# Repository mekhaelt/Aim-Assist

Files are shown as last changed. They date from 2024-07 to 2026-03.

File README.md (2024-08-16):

# Aim Assist

<p align="center">
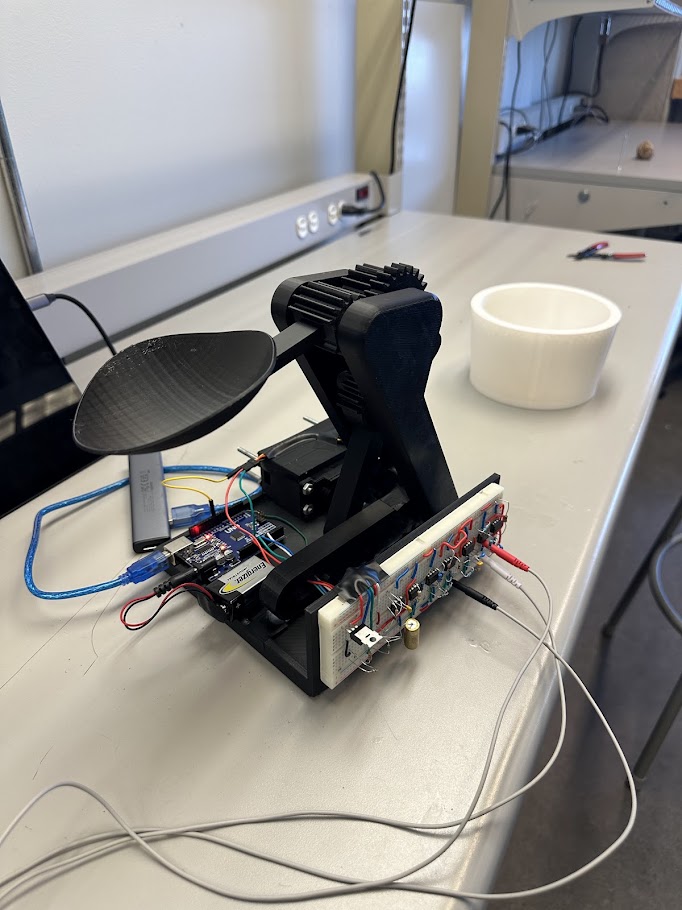
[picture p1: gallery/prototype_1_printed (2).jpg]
  
</p>

## Overview

The Aim Assist project develops a prosthetic arm that replicates the biomechanics of a human arm to shoot a basketball. Designed for individuals with upper limb disabilities or amputations, this prosthetic enhances physical activity and psychological well-being by enabling participation in sports.

## Features

-   **Biomechanical Accuracy**: Mimics natural arm movements including elbow and shoulder flexion and wrist flick.
-   **Customizable Settings**: Engineered to adjust for optimal release speed, angle, and spin.
-   **Arduino Integration**: Uses Arduino Uno to synchronize motor movements with EMG signal inputs for real-time responsiveness.

## Technology Stack

-   **Mechanical Design**: Gears and linkages to simulate arm motion.
-   **Electronics**: Arduino Uno and Servo Motors (HS-805BB).
-   **Fabrication**: 3D printed with Polylactic Acid (PLA) for durability and lightness.

## Installation

```bash
git clone https://github.com/your-github/aim-assist.git
```

-   Assemble the hardware according to the diagrams provided in the `docs/assembly_instructions.pdf`.
-   Install Arduino dependencies.

## Usage

-   Attach the prosthetic arm following the personal fitting instructions.
-   Calibrate the EMG sensors as per the user guide.
-   Use the provided scripts to test and calibrate the shooting mechanism.

## Collaborators
- Raiyan A [Contact](mailto:raiyanjaz@gmail.com)
- Mekhael T [Contact](mailto:mekhaelt@gmail.com)

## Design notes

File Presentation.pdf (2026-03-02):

# Aim Assist

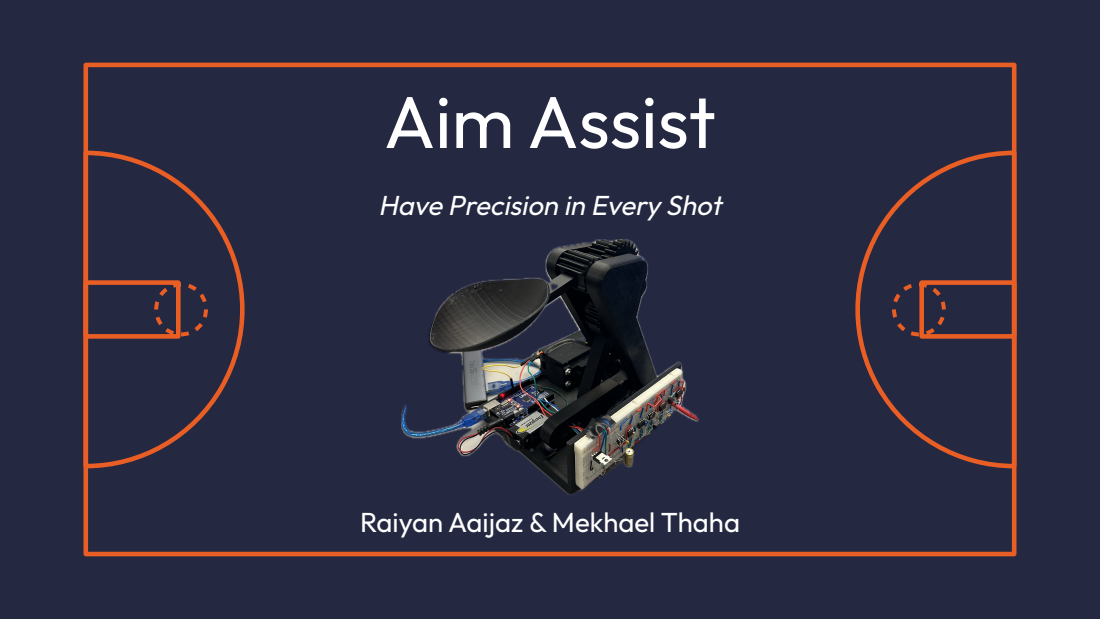
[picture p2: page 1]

Have Precision in Every Shot

Raiyan Aaijaz & Mekhael Thaha

# Objective and Requirements:

Develop a prosthetic arm capable of shooting a tennis ball-sized object with the technique of a basketball shot. The prosthetic should mimic the biomechanics of a human arm, ensuring consistent release speed, angle, and spin to achieve accurate and repeatable shots.

Torque: 2.57 N-m
Speed: 2.48 m/s
Range of Motion: 53 degree

# Engineering Requirements Calculations

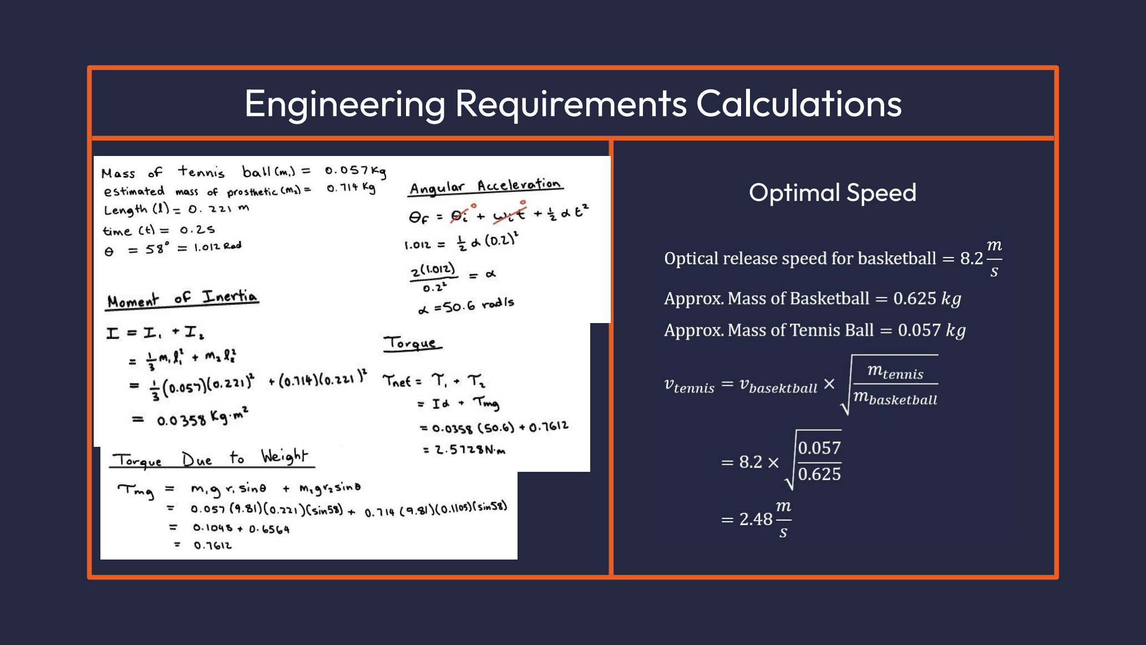
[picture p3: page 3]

## Optimal Speed

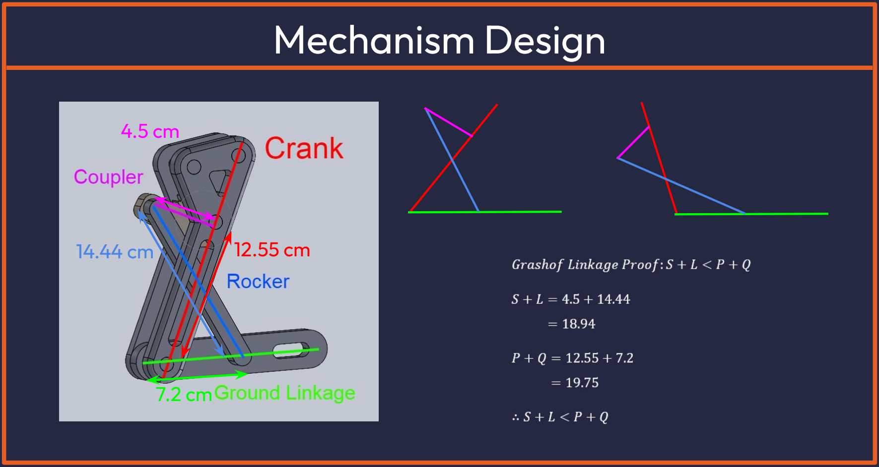
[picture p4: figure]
Mechanism Design

# Material and Servo Analysis

We chose 3D printing using Polylactic Acid (PLA) for all components due to several advantages:
- Ease of Manufacture: The gears designed have large teeth, which eliminates the need for high-precision cutting tools such as laser cutters.
- Material Properties: PLA is a lightweight material. When printed with increased infill, it provides the necessary sturdiness for our application.
- Cost-Effectiveness: PLA is a cost-effective choice for prototyping, allowing for efficient and economical production of design iterations.
Material Selection | Servo Selection
| Chosen Motor: HS-805BB Servo Motor ● Torque requirement needed for motor was 2.57 N-m ● HS-805BB gets 1.95 Nm at 4.8 V, 2.52 Nm at 6.0 V ● Though it is the heaviest option at 152 grams, it is manageable. Lighter motors are inadequate in other areas.

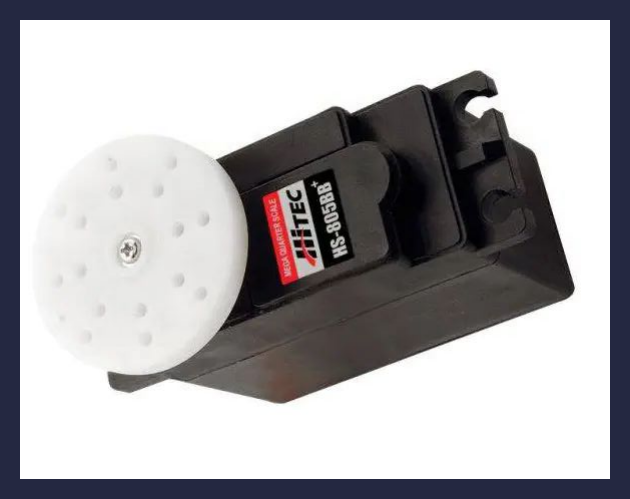
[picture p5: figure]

# Design Process and Iterations

Iteration 1:

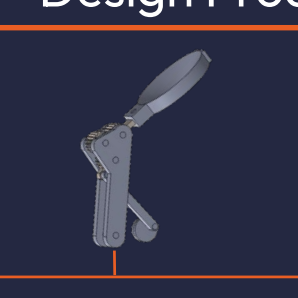
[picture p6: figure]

- Motor was planned to be connected at the linkage directly rather than the arm.
- The arms were kept stationary.
- Hand design was much larger than needed.

Iteration 2:

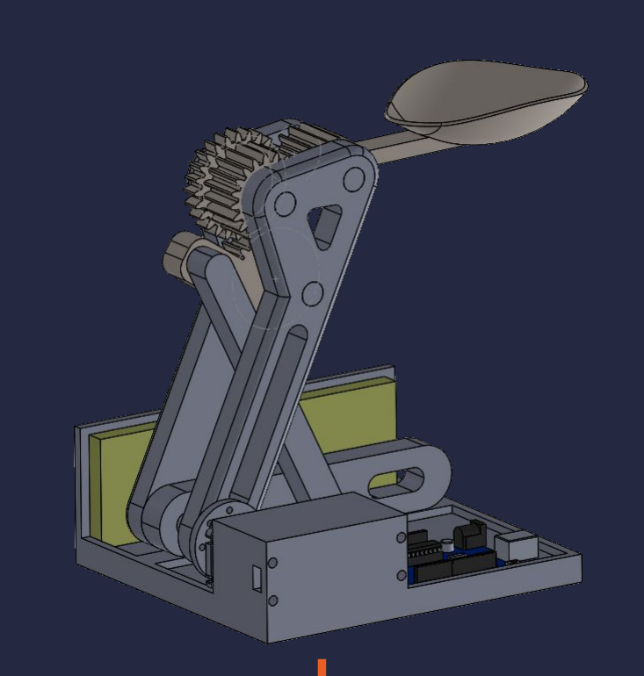
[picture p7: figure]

- Created a base to store Arduino, breadboard, and motor.
- Improved the hand design
- Moved the motor to add additional motion
- Scaled the design by 80% to minimize the weight.

# Arduino Code

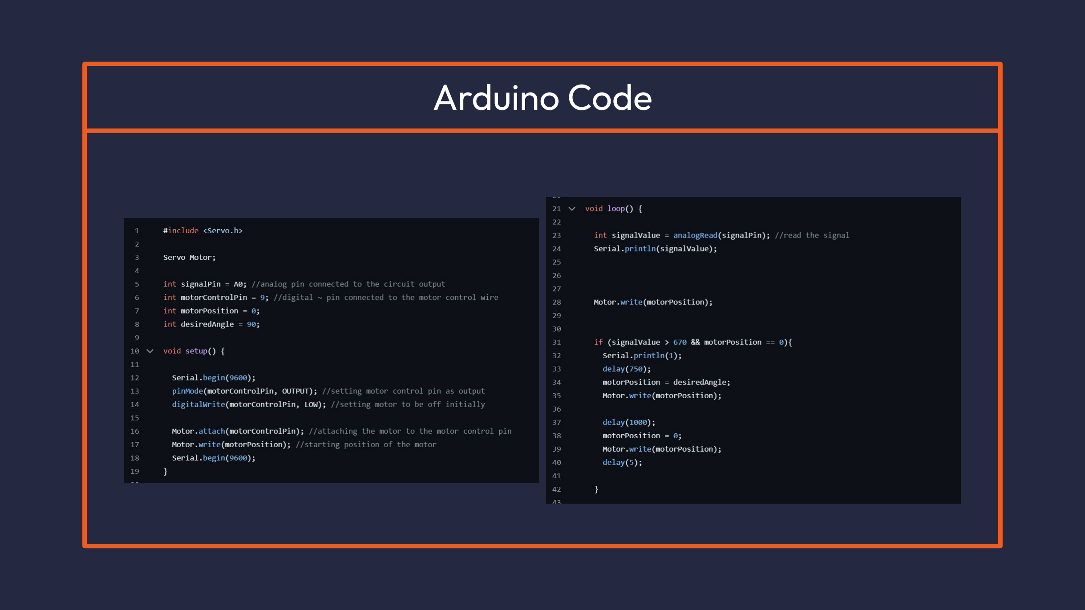
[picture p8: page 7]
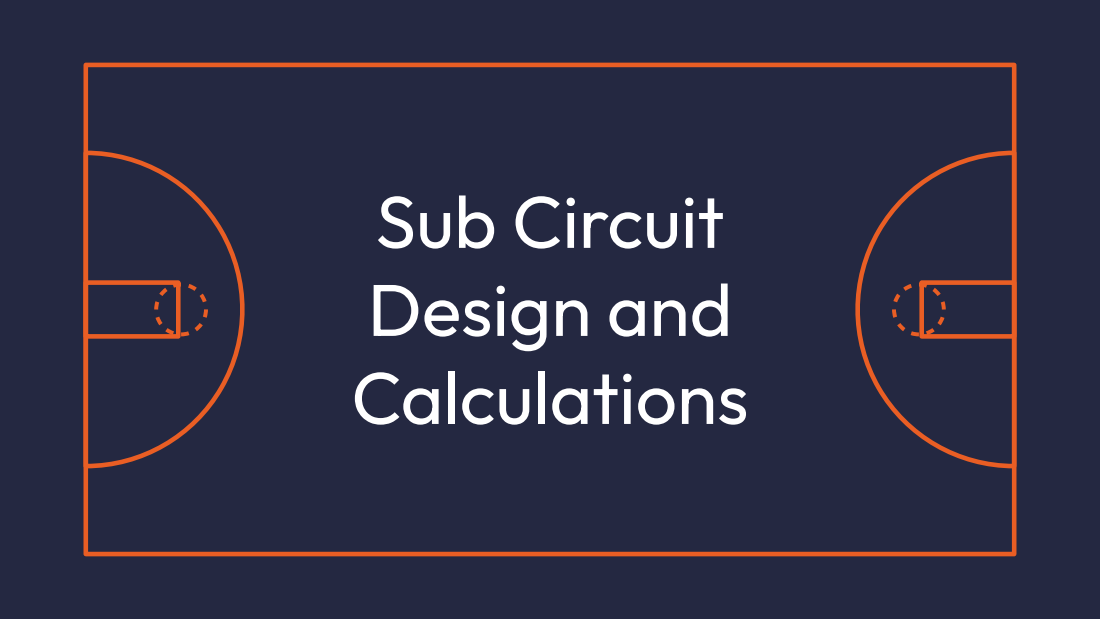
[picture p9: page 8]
Sub Circuit Design and Calculations

# Instrumentation Amplifier + Virtual Ground

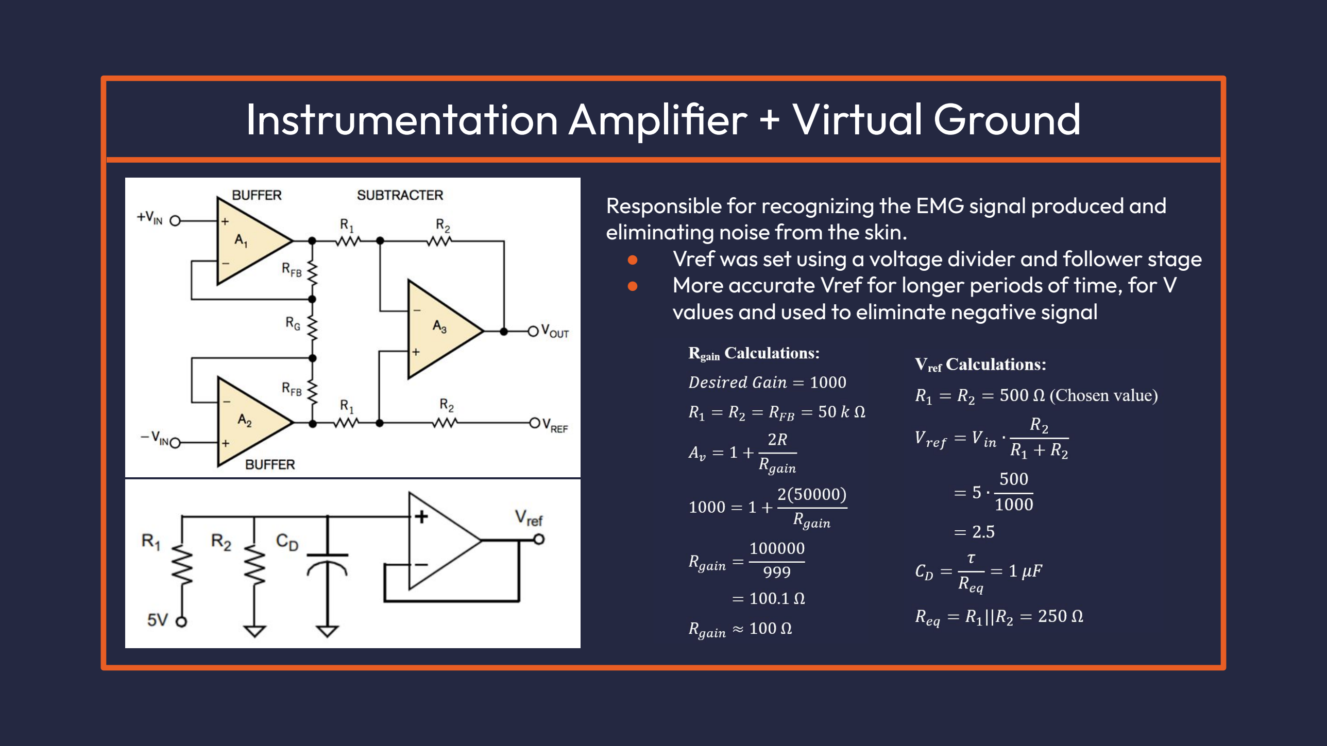
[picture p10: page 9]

Responsible for recognizing the EMG signal produced and eliminating noise from the skin.
- Vref was set using a voltage divider and follower stage
- More accurate Vref for longer periods of time, for V values and used to eliminate negative signal

# BandPass Filter (20 Hz and 500 Hz)

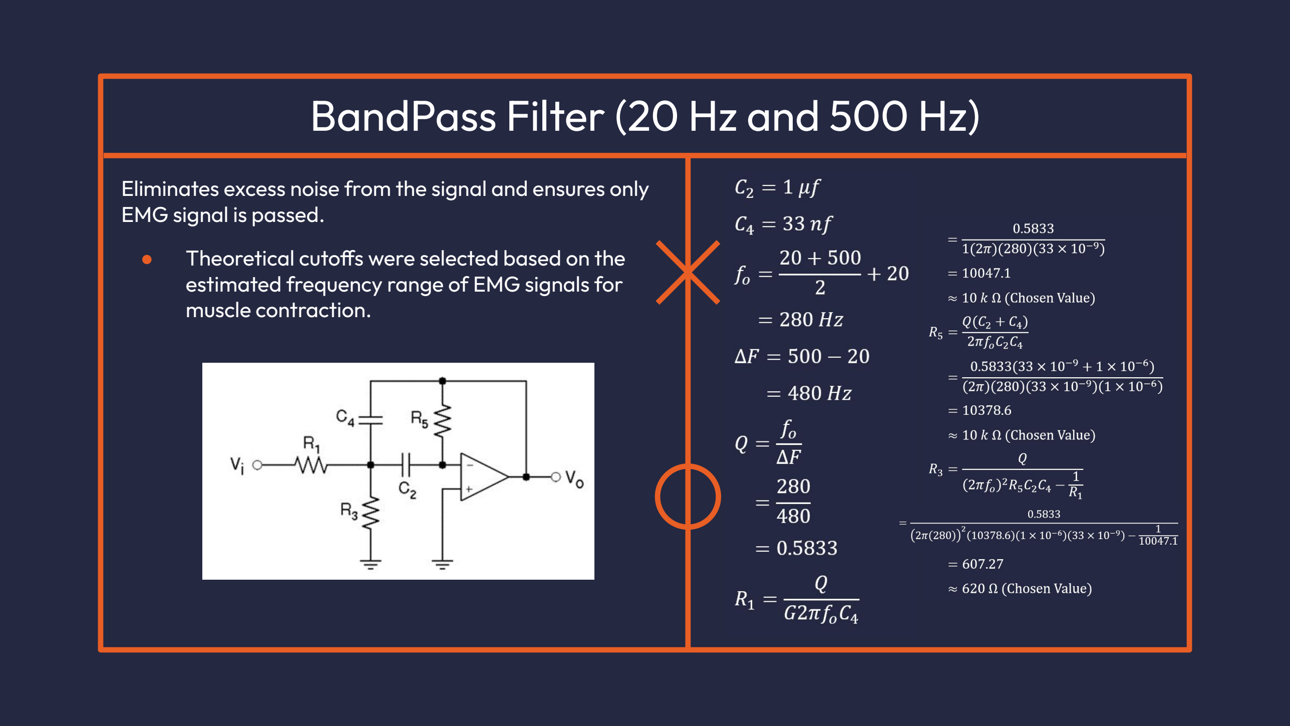
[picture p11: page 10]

Eliminates excess noise from the signal and ensures only EMG signal is passed.
- Theoretical cutoffs were selected based on the estimated frequency range of EMG signals for muscle contraction.

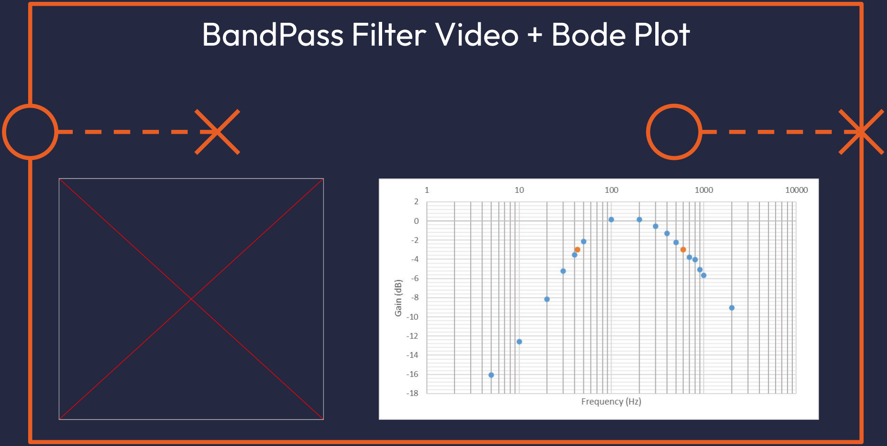
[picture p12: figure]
BandPass Filter Video + Bode Plot

# Full-Wave Rectifier

Responsible for cleaning up signal quality and emphasizing peaks of the EMG signal while maintaining integrity of the signal
- Gain of -1
- -2 from half wave rectifier
- +1 from summing amplifier

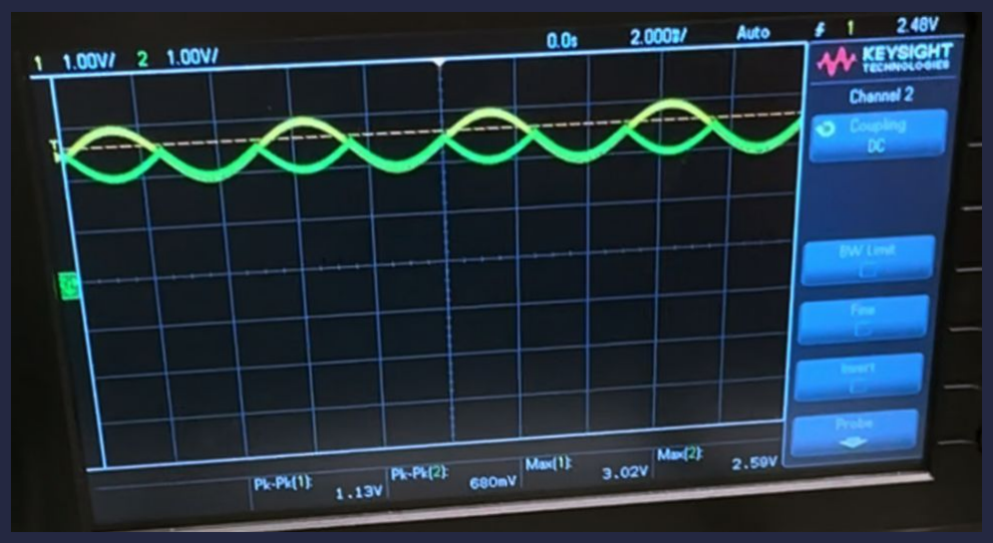
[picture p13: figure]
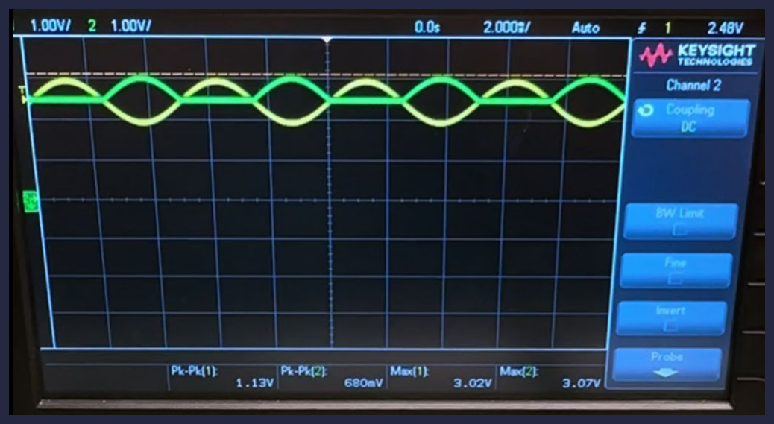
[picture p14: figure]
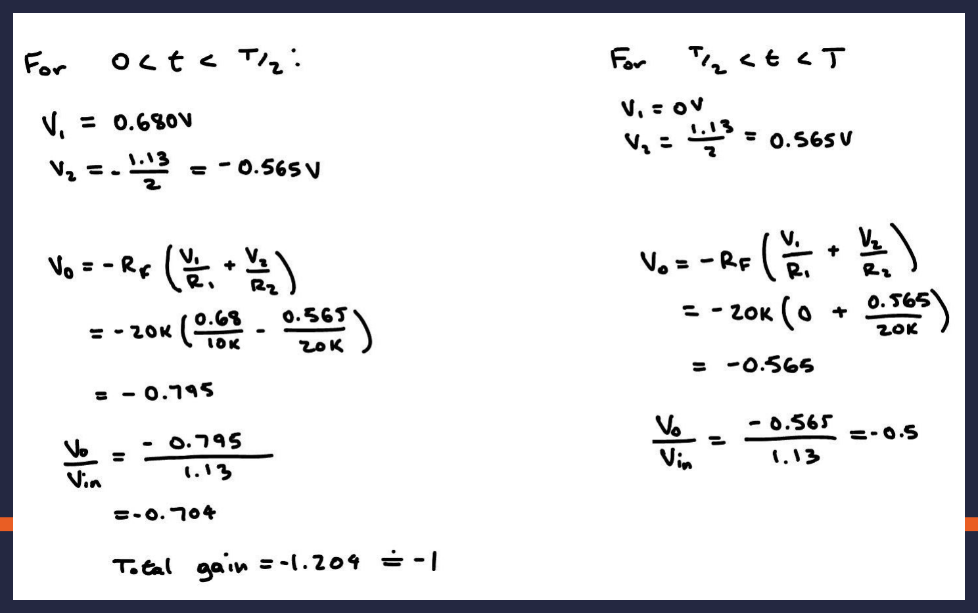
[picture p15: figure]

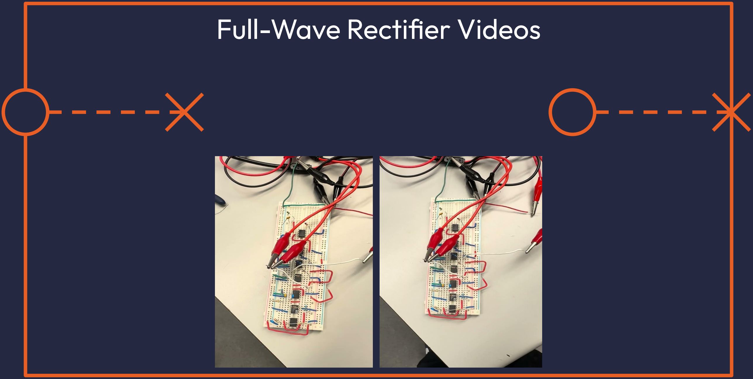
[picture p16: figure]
Full-Wave Rectifier Videos

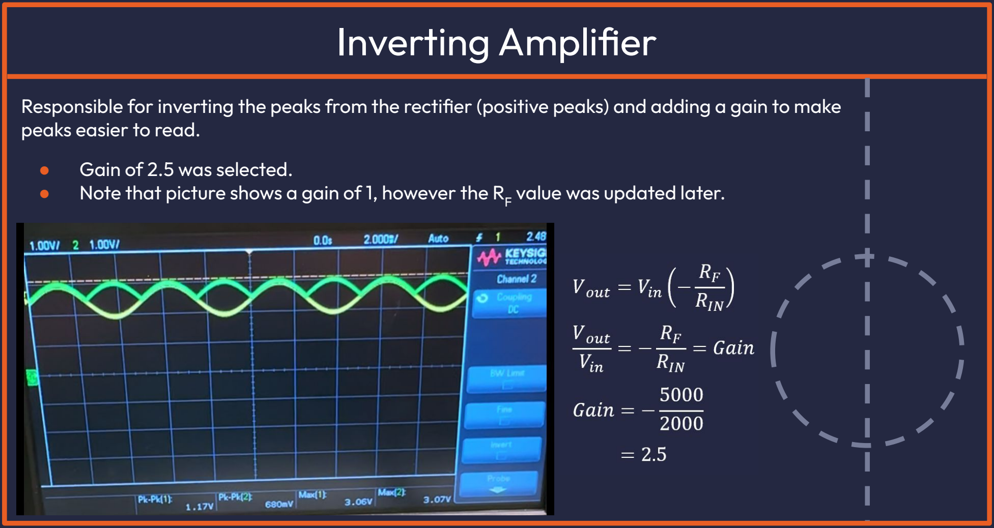
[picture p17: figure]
Inverting Amplifier; peaks easier to read.; ● Gain of 2.5 was selected.; value was updated later.

Responsible for inverting the peaks from the rectifier (positive peaks) and adding a gain to make

- Note that picture shows a gain of 1, however the RF

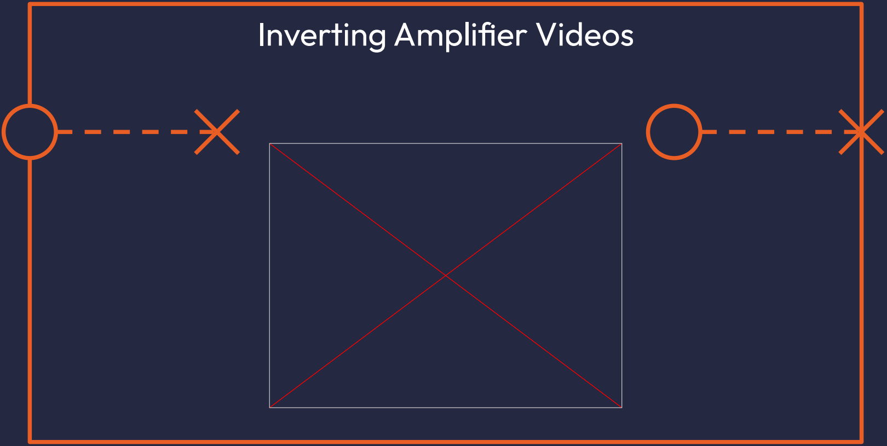
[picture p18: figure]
Inverting Amplifier Videos

# Peak Detector

Responsible for identifying the peaks of the signal corresponding to muscle contractions and holding for a fixed amount of time before searching for the new peak
- Allows voltages to be read once a threshold voltage of ~3.5 is achieved.
- Triggers the mechanism to contract after a short delay.
- R was added to allow for the peaks to hold for longer (takes longer for capacitor to drain out)

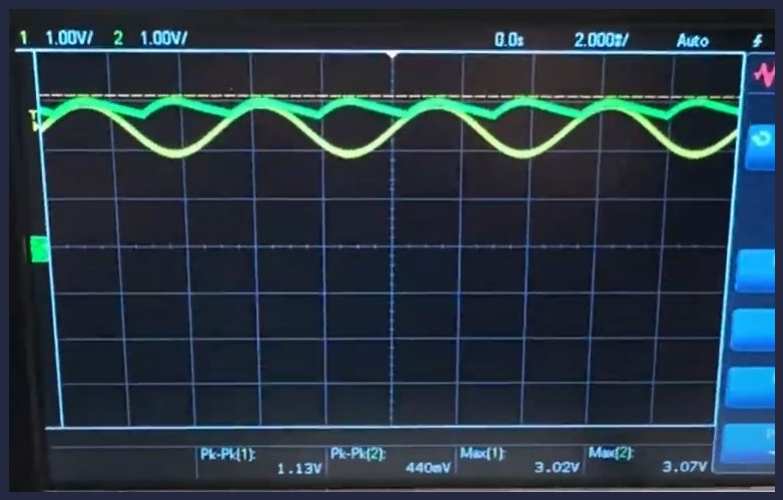
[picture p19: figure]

Time Constant Calculations:

τ = RC
τ = 1*10⁶

(47*10⁻⁶)
τ = 47s

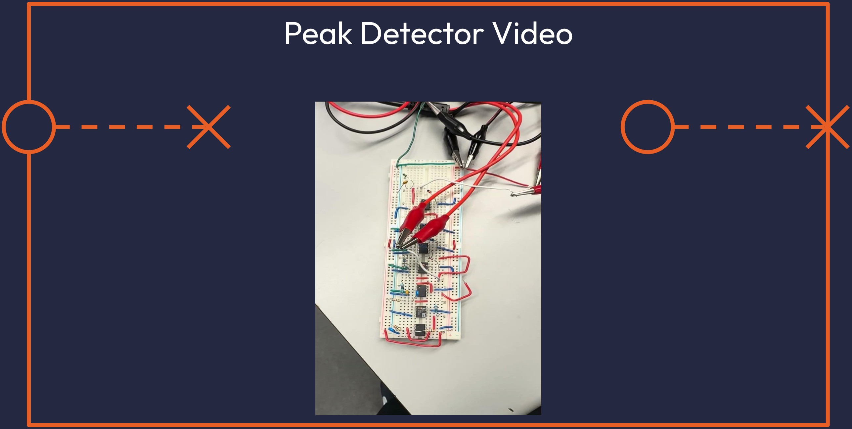
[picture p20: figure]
Peak Detector Video

# Final Circuit Schematic

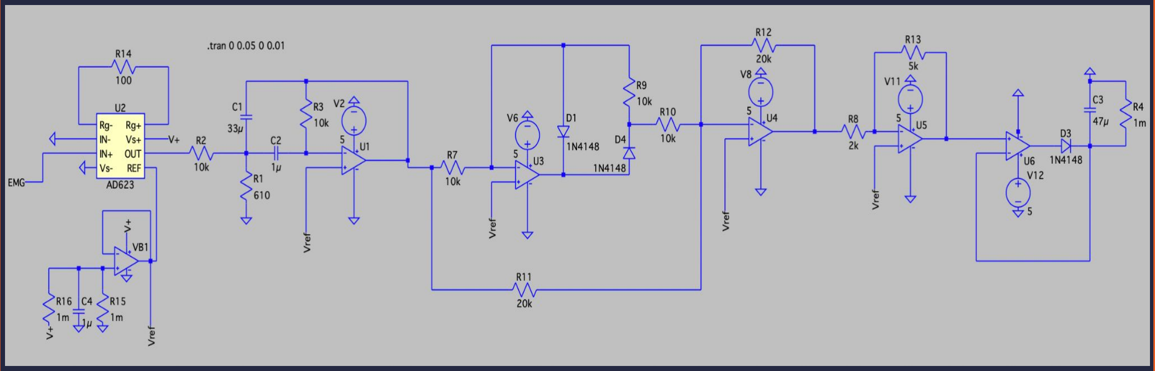
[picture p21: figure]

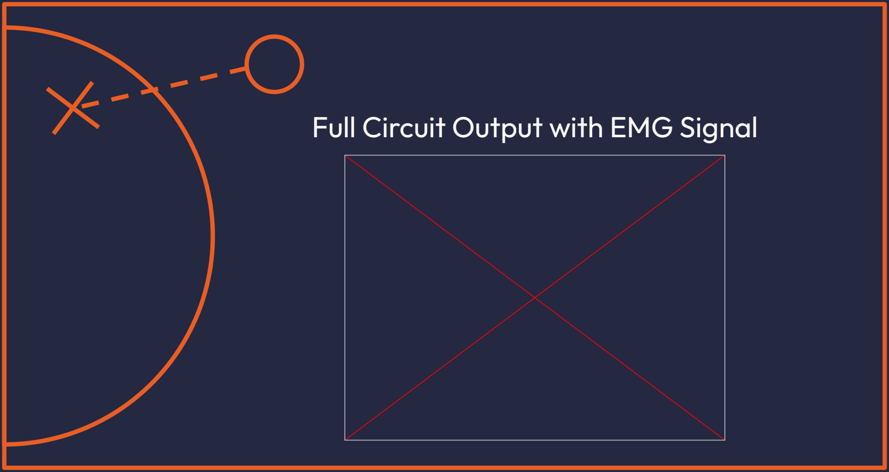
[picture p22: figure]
Full Circuit Output with EMG Signal

# Finish Product Demo

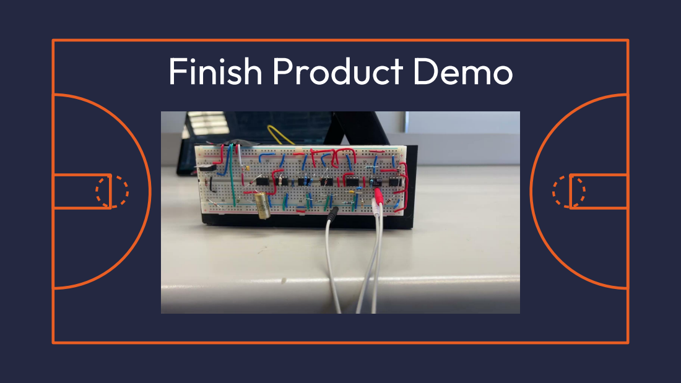
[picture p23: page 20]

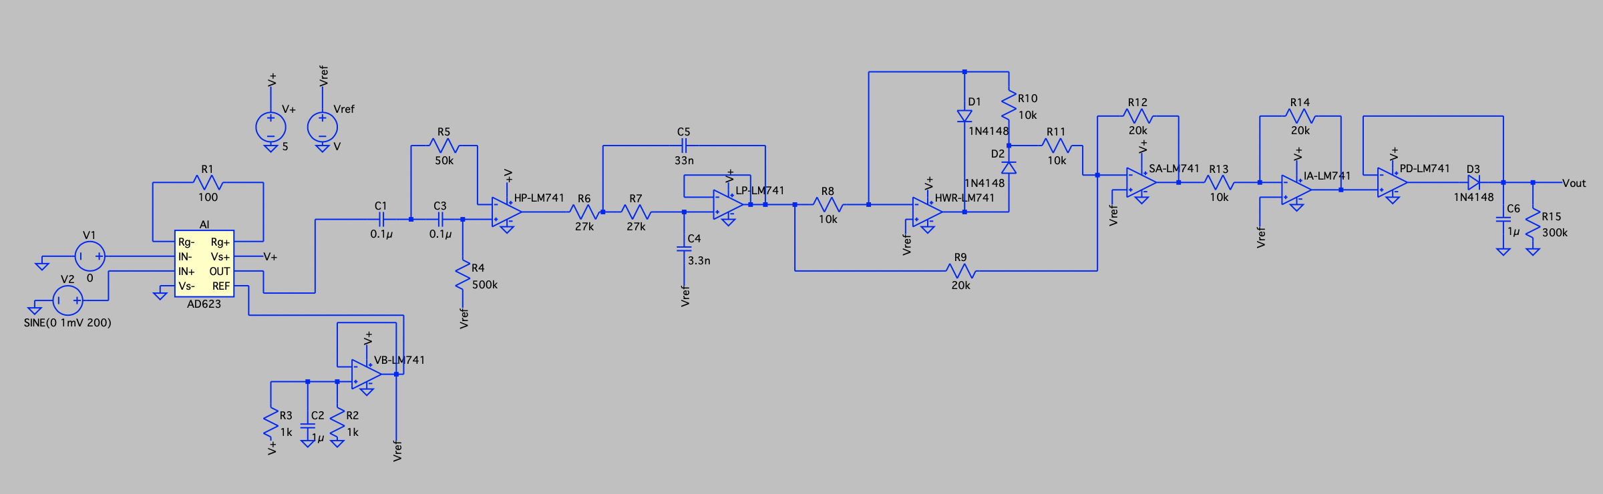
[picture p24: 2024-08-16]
gallery/circuit_schematic.png

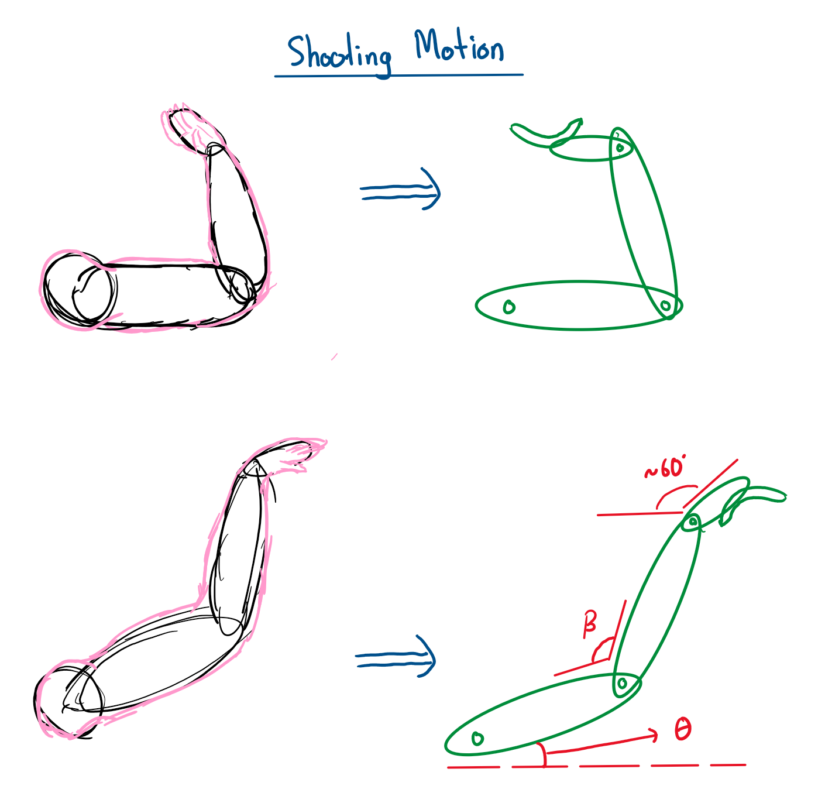
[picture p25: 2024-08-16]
gallery/ideation_1.png

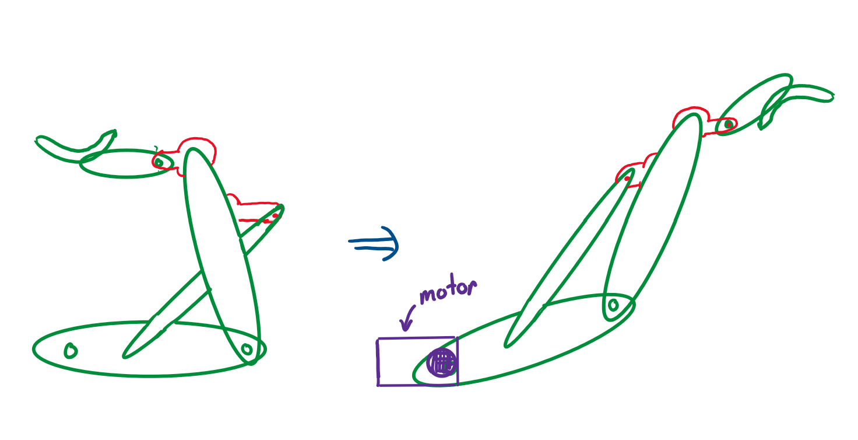
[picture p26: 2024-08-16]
gallery/ideation_2.png

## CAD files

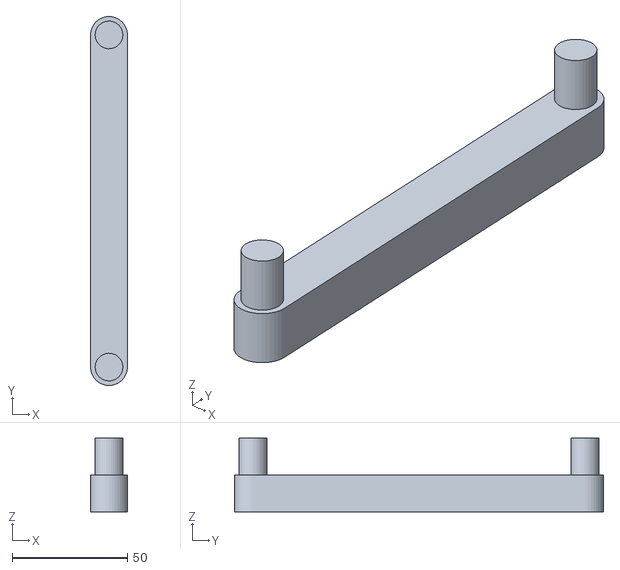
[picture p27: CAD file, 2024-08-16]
hardware/stl_files/crank_main.STL
16.0 x 160.0 x 32.0

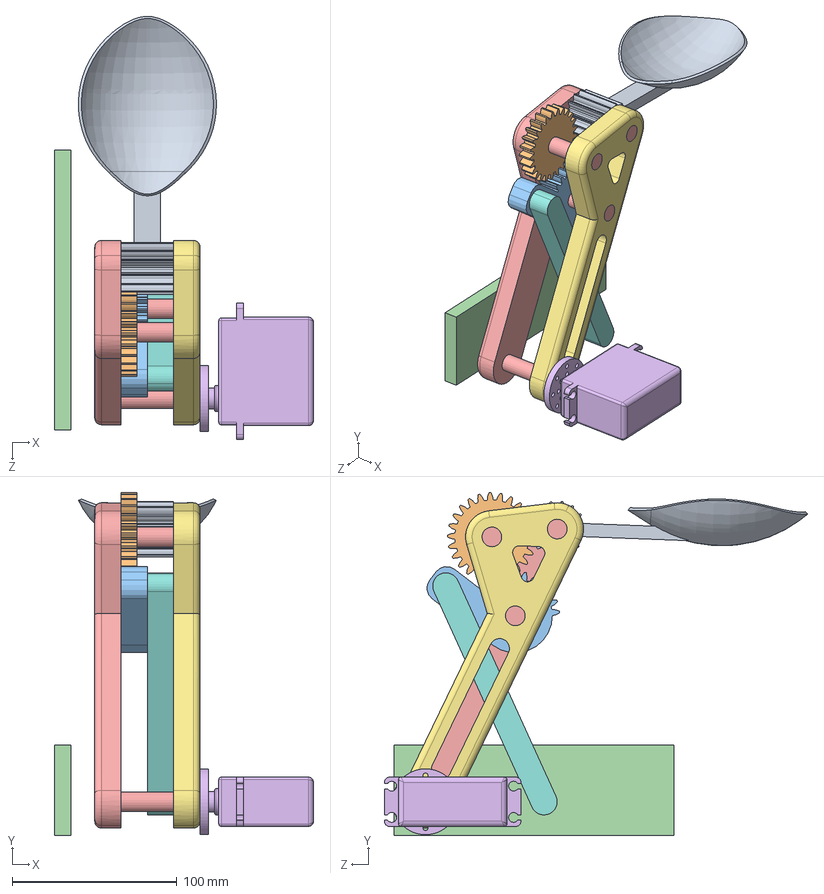
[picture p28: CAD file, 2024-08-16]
hardware/solidworks_design_files/aim_assist_assembly.SLDASM
157.4 x 208.4 x 257.2 mm
crank_main
left_lower_arm
Hitec_HS-805BB_servo_motor
right_lower_arm
breadboard_template
gear_crank
gear_large
hand_w_gear

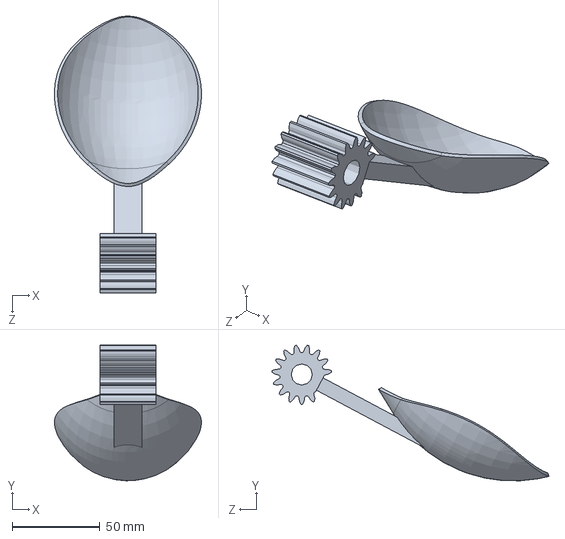
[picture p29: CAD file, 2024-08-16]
hardware/solidworks_design_files/hand_w_gear.SLDPRT
83.8 x 77.3 x 157.9 mm

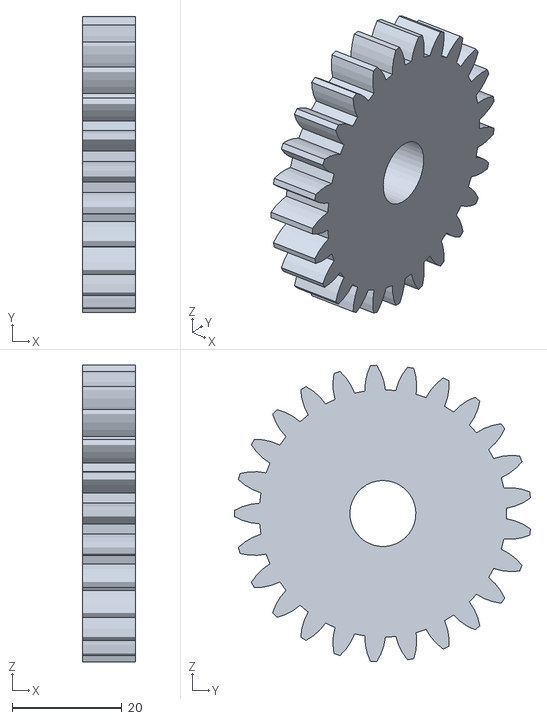
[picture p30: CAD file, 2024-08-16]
hardware/stl_files/gear_large.STL
9.60 x 53.8 x 54.0

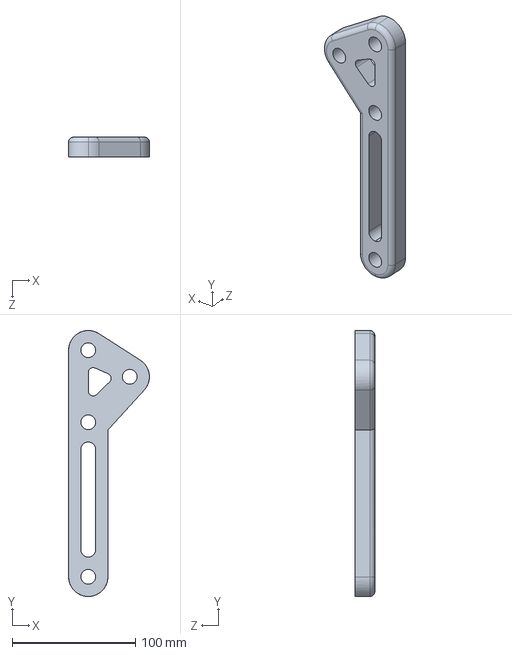
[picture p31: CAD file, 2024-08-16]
hardware/solidworks_design_files/left_lower_arm.SLDPRT
65.7 x 216.0 x 16.0 mm

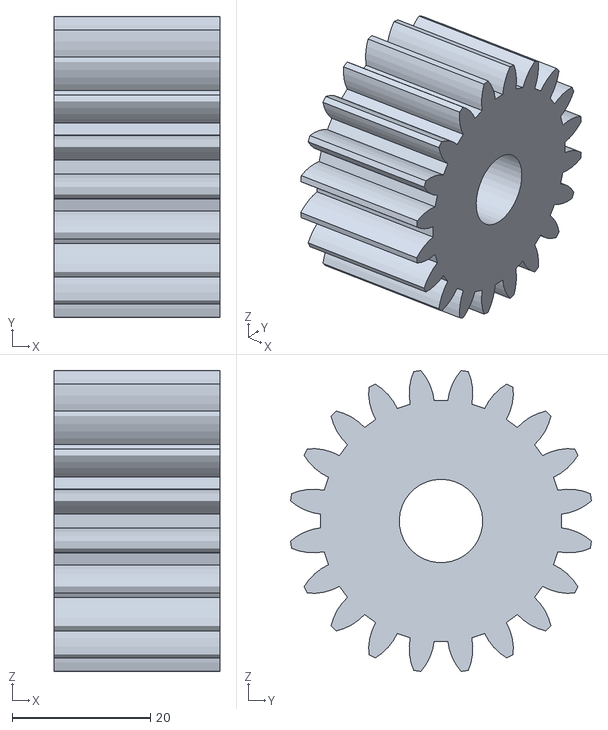
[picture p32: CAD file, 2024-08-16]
hardware/stl_files/gear_small.STL
24.0 x 43.6 x 43.6

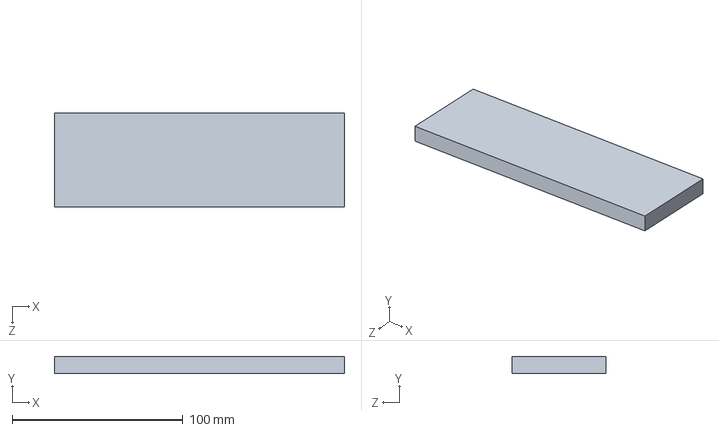
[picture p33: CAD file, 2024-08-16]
hardware/solidworks_design_files/breadboard_template.SLDPRT
170.0 x 10.0 x 55.0 mm

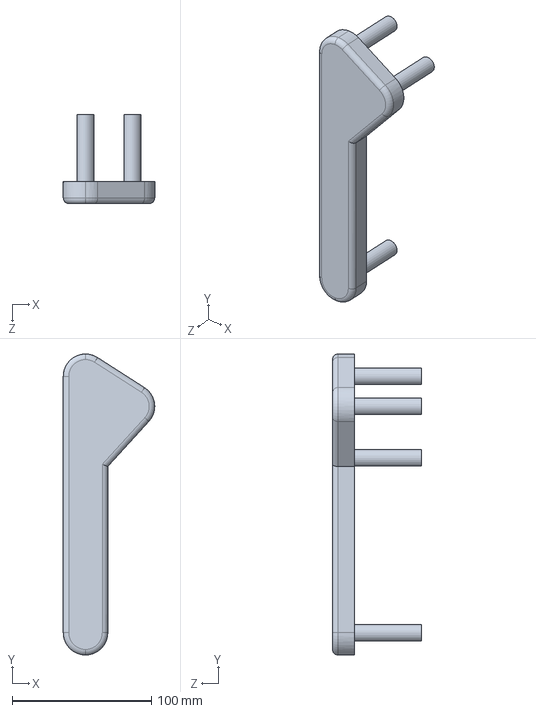
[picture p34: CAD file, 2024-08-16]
hardware/solidworks_design_files/right_lower_arm.SLDPRT
65.7 x 216.0 x 64.0 mm

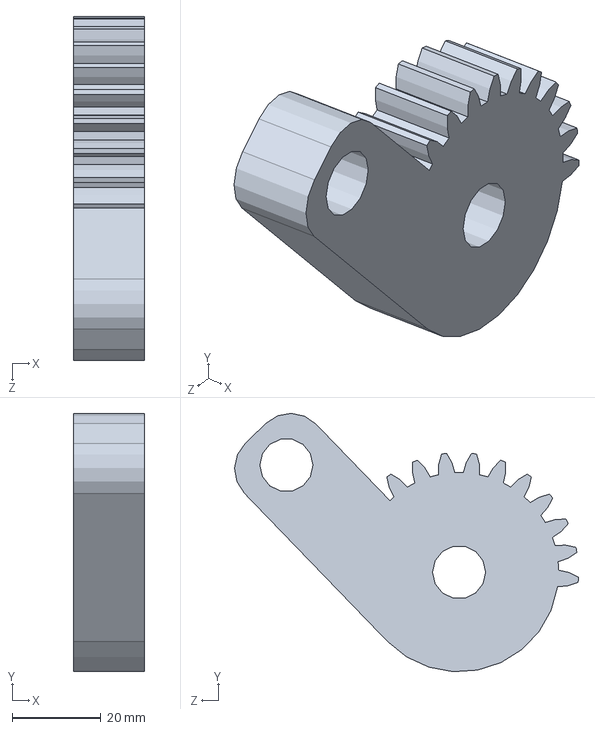
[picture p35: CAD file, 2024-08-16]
hardware/solidworks_design_files/gear_crank.SLDPRT
16.0 x 58.3 x 77.7 mm

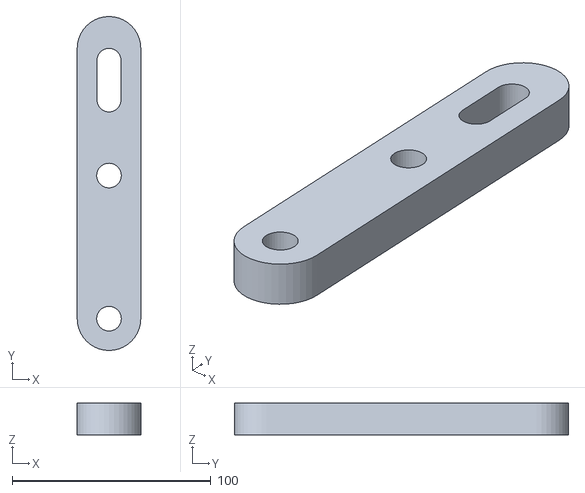
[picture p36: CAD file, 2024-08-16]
hardware/stl_files/upper_arm_base.STL
32.0 x 168.0 x 16.0

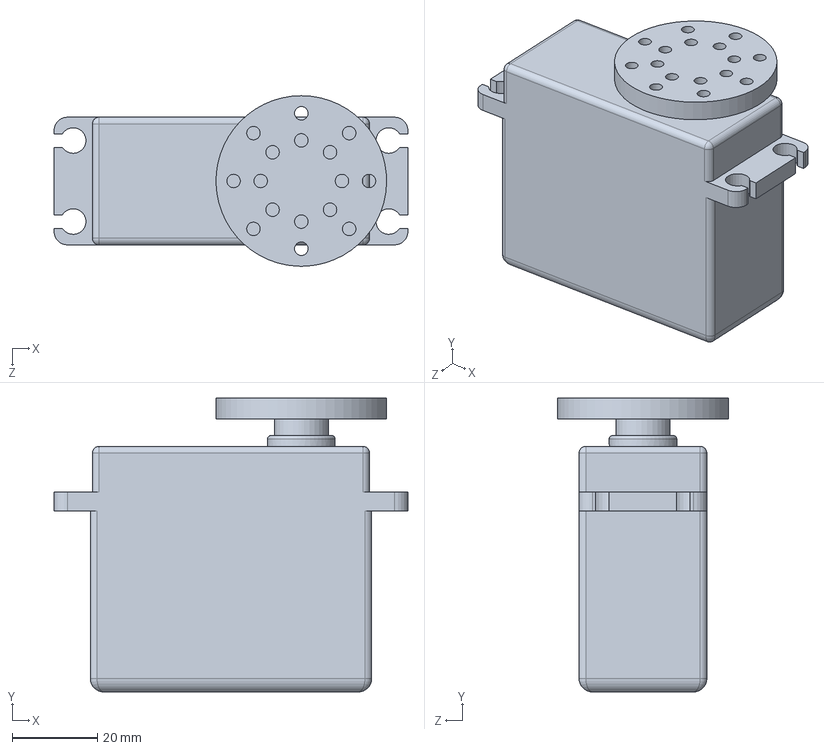
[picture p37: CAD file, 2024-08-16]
hardware/solidworks_design_files/Hitec_HS-805BB_servo_motor.SLDPRT
83.0 x 68.9 x 40.0 mm

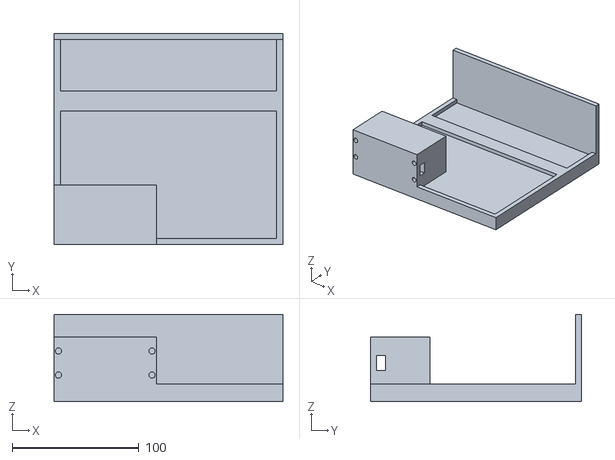
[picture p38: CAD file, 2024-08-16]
hardware/stl_files/base.STL
181.0 x 167.0 x 69.0

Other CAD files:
hardware/solidworks_design_files/crank_main.SLDPRT
hardware/stl_files/hand_w_gear.STL
hardware/solidworks_design_files/gear_large.SLDPRT
hardware/stl_files/left_lower_arm.STL
hardware/stl_files/right_lower_arm.STL
hardware/stl_files/gear_crank.STL
hardware/solidworks_design_files/arduino_uno_template.SLDPRT
hardware/solidworks_design_files/base.SLDPRT
hardware/solidworks_design_files/gear_small.SLDPRT
hardware/solidworks_design_files/upper_arm_base.SLDPRT

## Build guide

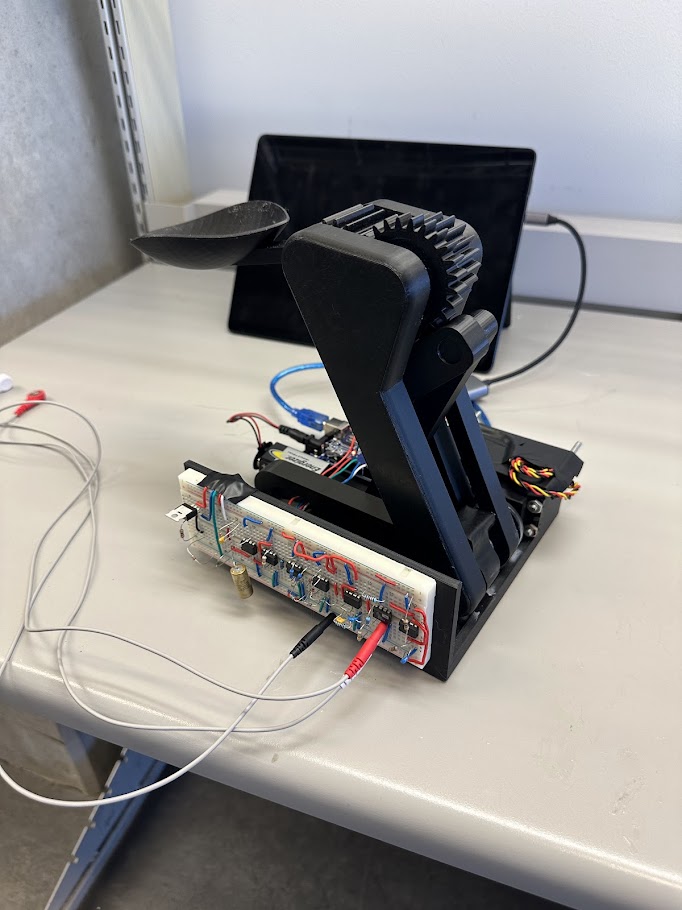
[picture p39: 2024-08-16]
gallery/prototype_1_printed (1).jpg

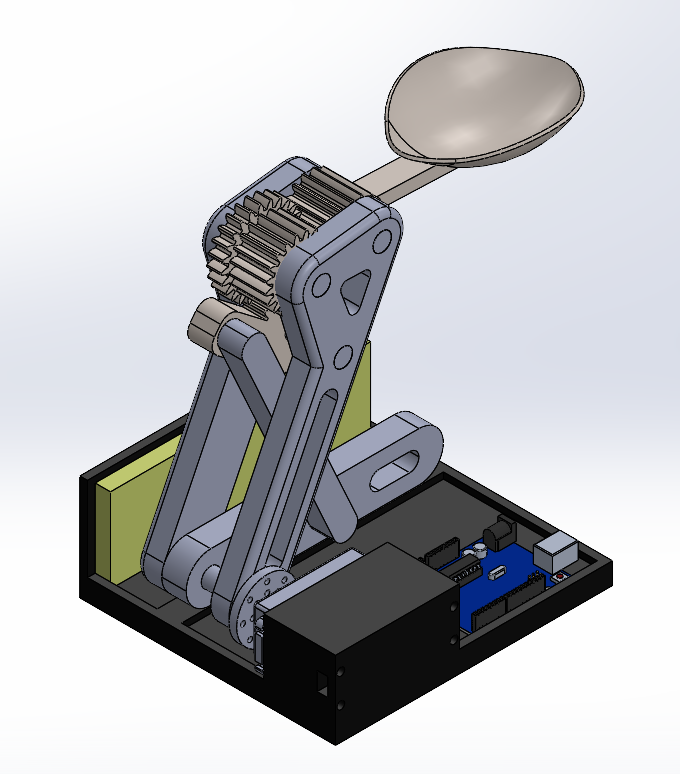
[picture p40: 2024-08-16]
gallery/prototype_1_solidworks_assembly.png

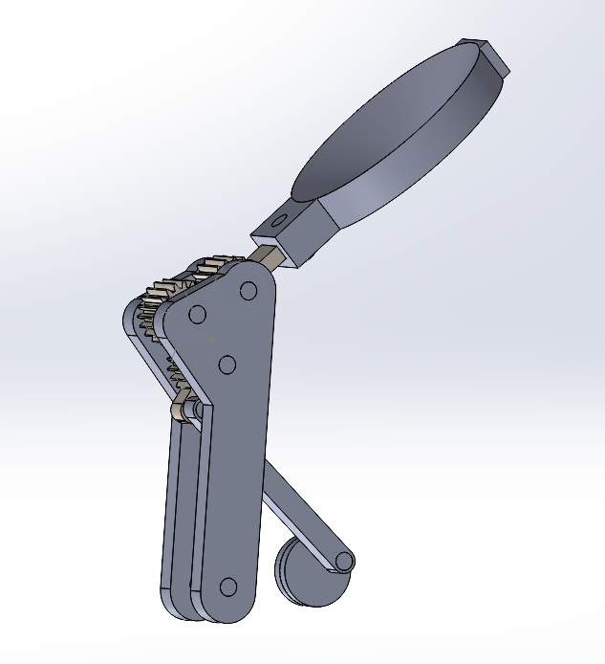
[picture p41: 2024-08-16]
gallery/prototype_0_solidworks_assembly.png

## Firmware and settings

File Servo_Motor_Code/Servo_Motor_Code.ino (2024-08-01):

#include <Servo.h>

Servo Motor;

// Analog pin connected to the circuit output
int signalPin = A0; 

// Digital pin connected to the motor control wire
int motorControlPin = 9; 
int motorPosition = 0; 
int desiredAngle = 90;

void setup() {
  Serial.begin(9600);

  // Set motor control pin as output
  pinMode(motorControlPin, OUTPUT);  
  // Initialize motor to be off
  digitalWrite(motorControlPin, LOW); 

  // Attach the motor to the motor control pin
  Motor.attach(motorControlPin); 
  // Set starting position of the motor
  Motor.write(motorPosition); 
}

void loop() {
  // Read the analog signal
  int signalValue = analogRead(signalPin); 
  // Print the signal value for debugging
  Serial.println(signalValue);

  // Write current motor position
  Motor.write(motorPosition);
  
  // Check if signal value is above threshold and motor is in the initial position
  if (signalValue > 670 && motorPosition == 0) {
    // Print status for debugging
    Serial.println(1);
    // Delay for stabilization
    delay(750);
    // Move motor to desired angle
    motorPosition = desiredAngle;
    Motor.write(motorPosition);

    // Hold position before resetting
    delay(1000);
    // Reset motor position
    motorPosition = 0;
    Motor.write(motorPosition);
    // Small delay for smooth movement
    delay(5);
  } 
  // Delay before next loop iteration
  delay(3000);
}

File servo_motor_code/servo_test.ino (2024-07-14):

#include <Servo.h>

int buttonPin = 4;
int button2Pin = 7;

int servoPin = 3;
Servo Servo1;
int servoPosition = 0;

void setup() {
  // put your setup code here, to run once:
  Servo1.attach(servoPin);
  Servo1.write(servoPosition);

  Serial.begin(9600);

}

void loop() {
  // put your main code here, to run repeatedly:
  int buttonState = digitalRead(buttonPin);
  int button2State = digitalRead(button2Pin);

  Servo1.write(servoPosition);

  if (buttonState == HIGH && servoPosition < 180) {
    Servo1.write(servoPosition);
    servoPosition++;
    delay(5);
  } else if (button2State == HIGH && servoPosition >= 0) {
    Servo1.write(servoPosition);
    servoPosition--;
    delay(5);
  }

}

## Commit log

2024-07-14 Created Servo Motor Code
2024-07-18 Update Servo_Motor_Code.ino
    Updated Arduino code
2024-07-18 Update Servo_Motor_Code.ino
    Fixed errors
    [Servo_Motor_Code.ino]
2024-07-18 Update Servo_Motor_Code.ino
    Fixed bugs
    [Servo_Motor_Code.ino]
2024-08-16 Update and rename Servo_Motor_Code.ino to emg_integration.ino
2024-08-16 added design files and STL files
    [Hitec_HS-805BB_servo_motor.SLDPRT, aim_assist_assembly.SLDASM, arduino_uno_template.SLDPRT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]
2024-08-16 Added Circuits Schematic
2024-08-16 Added Circuit Schematic
2024-08-16 Move gallery/Schematic_AimAssist.asc
